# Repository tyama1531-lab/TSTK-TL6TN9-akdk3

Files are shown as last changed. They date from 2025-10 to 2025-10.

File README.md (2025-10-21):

# TSTK-TL6TN9

Generated by [Auto-Keyboard-Design-Kit](https://auto-kdk.pages.dev/)

## Preview

- 3D View

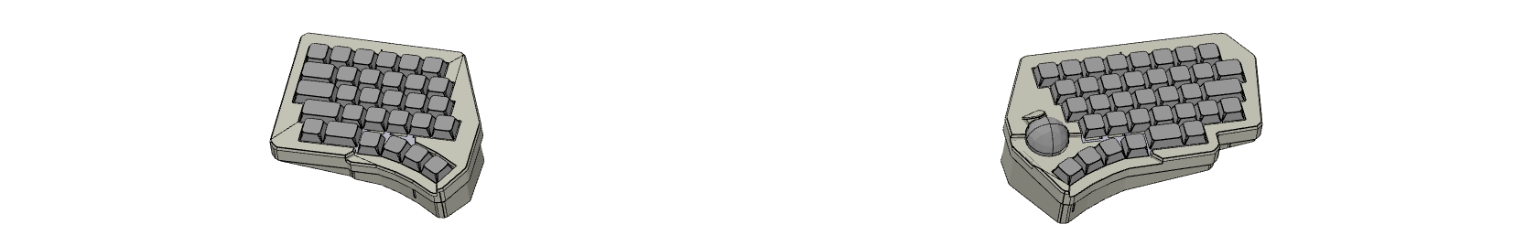
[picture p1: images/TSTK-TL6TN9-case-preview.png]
Case Preview


- Top View

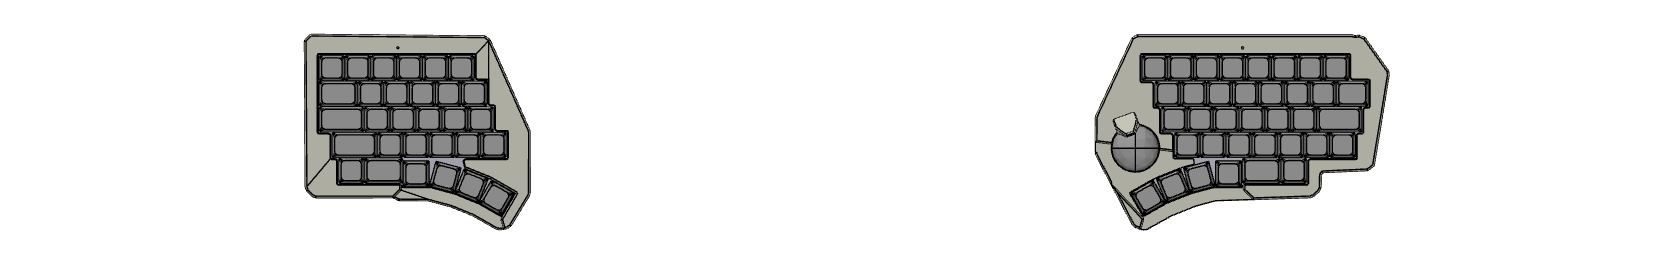
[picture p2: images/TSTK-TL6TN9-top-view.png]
Top View


## Parts List

|Part|Quantity|
|---|---|
|wireless controller|2|
|Conthrough(2.5mm, 9pin)|4|
|Battery|2|
USB-C cable|1|
|MX switch and MX socket|58|
|Choc V2 switch and Choc socket|8|
|Diode|66|
|Keycap|66|

## 機能

### PAW3222 トラックボール対応

このキーボードは右手側にPAW3222トラックボールを搭載し、高度な電源管理機能を備えています：

#### 🔋 電源管理
- **アイドルタイムアウト**: 5秒間操作がないと自動的にスリープモードに移行
- **スキャン頻度削減**: 非アクティブ時の消費電力を削減  
- **パワーコントロール**: ハードウェアレベルでのセンサーのスリープ/ウェイク制御

#### ⚙️ 設定オプション

以下の設定オプションが `boards/shields/tstk_tl6tn9/tstk_tl6tn9_right.conf` で利用可能です：

```properties
# PAW3222 アイドル・電源管理
CONFIG_PAW3222_IDLE_TIMEOUT_SECONDS=5     # アイドルタイムアウト（秒）
CONFIG_PAW3222_REDUCED_SCAN=y             # スキャン頻度削減を有効化
CONFIG_PAW3222_REDUCED_SCAN_MS=100        # 削減モード時のスキャン間隔（ミリ秒）
CONFIG_PAW3222_POWER_CTRL=y               # ハードウェア電源制御を有効化
```

#### 📊 デフォルト設定

| 設定項目 | 値 | 説明 |
|---|---|---|
| `IDLE_TIMEOUT_SECONDS` | 5 | アイドルモード移行までの時間 |
| `REDUCED_SCAN` | 有効 | モーションタイマーの最適化 |
| `REDUCED_SCAN_MS` | 100ms | スキャン頻度削減時のポーリング間隔 |
| `POWER_CTRL` | 有効 | ハードウェアスリープ/ウェイク制御 |

#### 🔧 カスタマイズ

電源管理の動作を変更するには：

1. `boards/shields/tstk_tl6tn9/tstk_tl6tn9_right.conf` を編集
2. CONFIG値を好みに応じて調整
3. `west build` でファームウェアを再ビルド

**バッテリー持続時間重視の設定例:**
```properties
CONFIG_PAW3222_IDLE_TIMEOUT_SECONDS=10    # より長いアイドルタイムアウト
CONFIG_PAW3222_REDUCED_SCAN_MS=200        # より遅いスキャン
```

**最大応答性重視の設定例:**
```properties
CONFIG_PAW3222_IDLE_TIMEOUT_SECONDS=30    # 最小限のアイドルタイムアウト
CONFIG_PAW3222_REDUCED_SCAN_MS=50         # より高速なスキャン
```

## ビルド方法

このファームウェアはwest ビルドシステムを使用するZMKとカスタムPAW3222ドライバーを使用しています。

### 前提条件
- West ビルド環境
- ZMK 開発環境のセットアップ

### ビルドコマンド
```bash
# 左手側ファームウェアのビルド
west build -b akdk_bt1 -- -DSHIELD=tstk_tl6tn9_left

# 右手側ファームウェアのビルド
west build -b akdk_bt1 -- -DSHIELD=tstk_tl6tn9_right

# 設定リセット用ファームウェア
west build -b akdk_bt1 -- -DSHIELD=settings_reset
```

### CI/CD
GitHub Actionsが push/PR 時に自動的にファームウェアをビルドします：
- 左手側: `tstk_tl6tn9_left-akdk_bt1-zmk.uf2`
- 右手側: `tstk_tl6tn9_right-akdk_bt1-zmk.uf2`  
- 設定リセット: `settings_reset-akdk_bt1-zmk.uf2`

## トラブルシューティング

### PAW3222 電源管理

**問題: アイドル後にトラックボールが反応しない**
- `CONFIG_PAW3222_POWER_CTRL=y` が有効になっているか確認
- アイドルタイムアウト設定を確認
- 電源状態の切り替えログを監視

**問題: バッテリー消耗が激しい**
- `CONFIG_PAW3222_IDLE_TIMEOUT_SECONDS` を増やす
- `CONFIG_PAW3222_REDUCED_SCAN_MS` を増やす
- `CONFIG_PAW3222_REDUCED_SCAN=y` が有効か確認

**問題: トラックボールの応答が遅い**
- `CONFIG_PAW3222_REDUCED_SCAN_MS` を減らす
- `CONFIG_PAW3222_IDLE_TIMEOUT_SECONDS` を減らす

### デバッグ
.conf` ファイルでデバッグログを有効化：

注: このリポジトリではログ設定は共通設定ファイル `config/prj.conf` に集約されています。個別のシールド設定（`boards/shields/.../*.conf`）で上書きすることも可能ですが、基本は `config/prj.conf` を編集してください。

```properties
# 有効にする場合（例）
CONFIG_ZMK_LOG_LEVEL_DBG=y
CONFIG_ZMK_USB_LOGGING=y
```

PAW3222関連のログメッセージを確認：
- `PAW32XX: idle timeout reached, entering idle`
- `PAW32XX: motion detected while idle -> waking up`
- `PAW32XX: sensor set to sleep`
- `PAW32XX: sensor wake request succeeded`

## ライセンス

[ライセンス情報をここに記載]

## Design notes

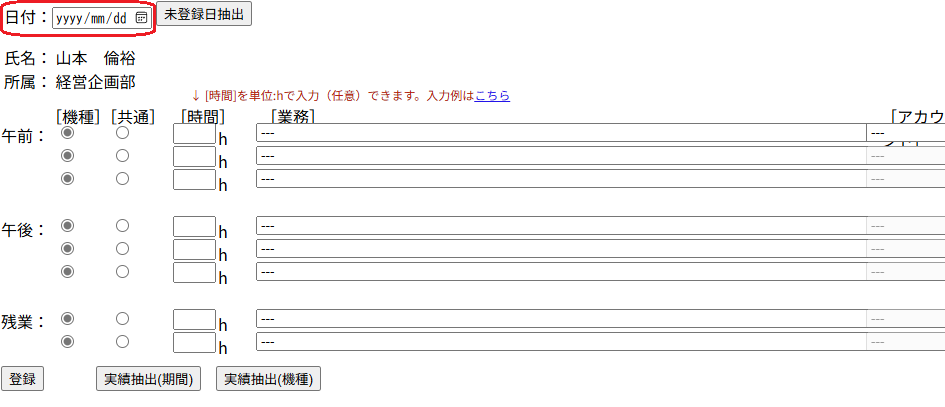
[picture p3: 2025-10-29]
images/Edgeモードで開いた画面.bmp

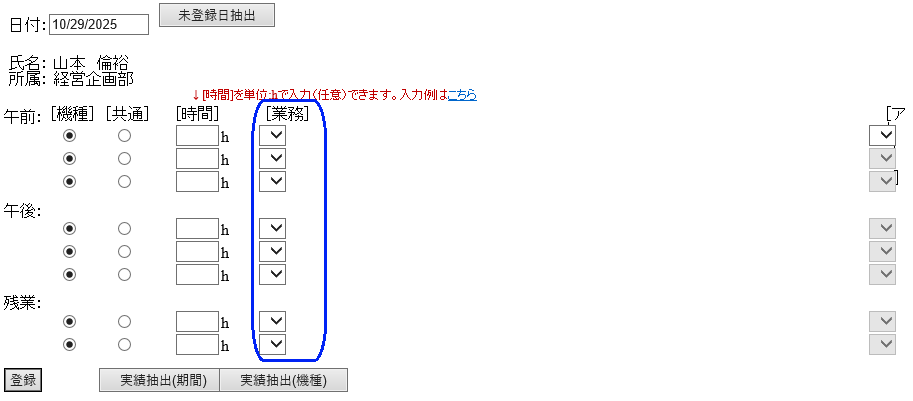
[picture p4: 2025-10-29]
images/IEモードで開いた画面.bmp

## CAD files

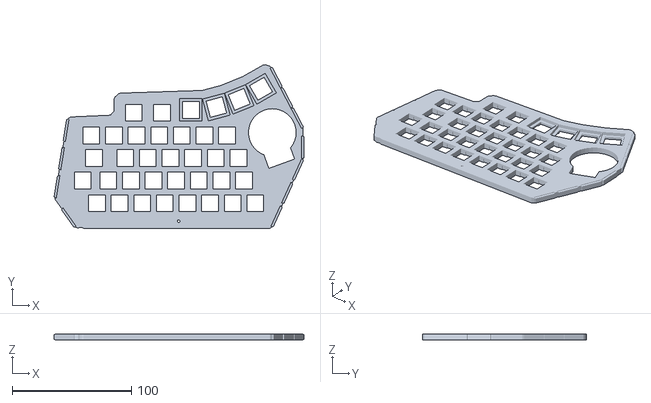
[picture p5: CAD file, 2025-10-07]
case/TSTK-TL6TN9-right-plate.stl
209.9 x 137.4 x 5.00

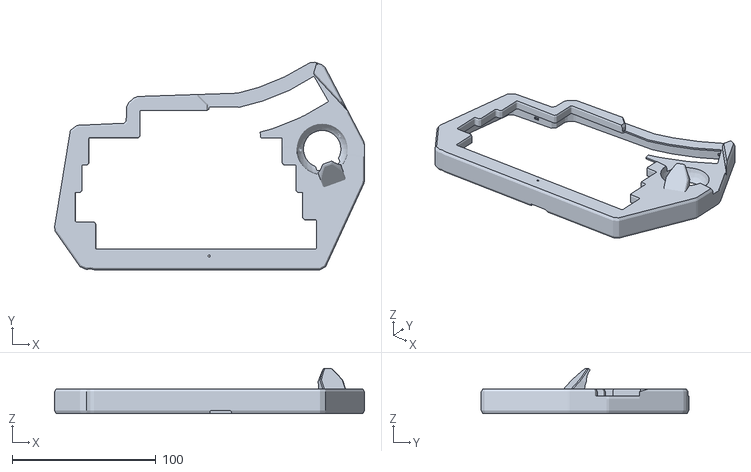
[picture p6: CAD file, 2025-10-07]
case/TSTK-TL6TN9-right-top-case.stl
215.6 x 144.3 x 31.3

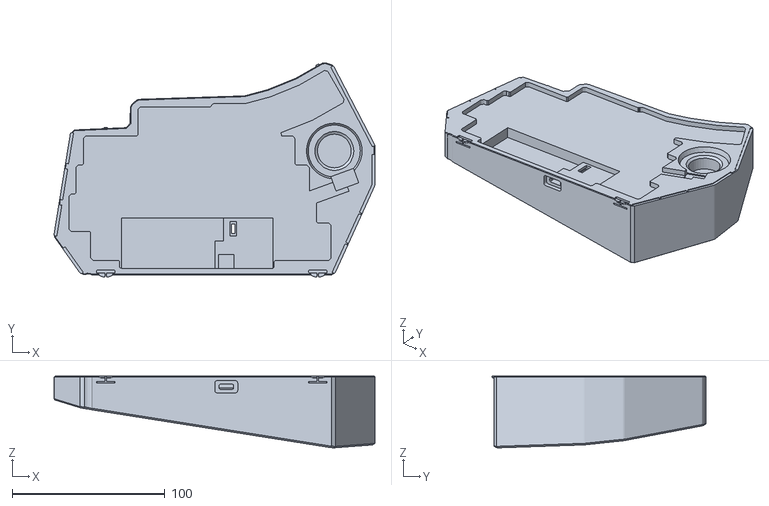
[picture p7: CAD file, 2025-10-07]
case/TSTK-TL6TN9-right-bottom-case.stl
210.0 x 140.2 x 47.0

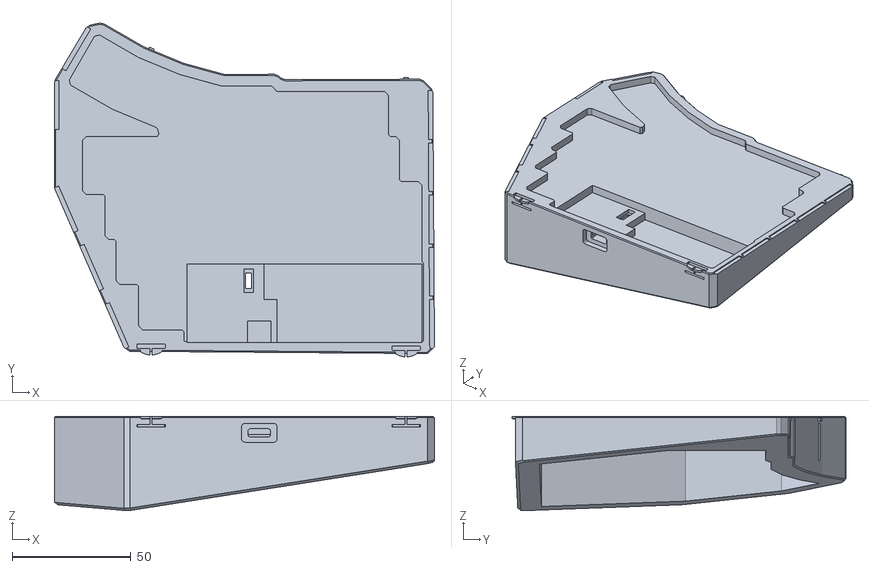
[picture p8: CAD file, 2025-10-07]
case/TSTK-TL6TN9-left-bottom-case.stl
160.1 x 140.6 x 39.8

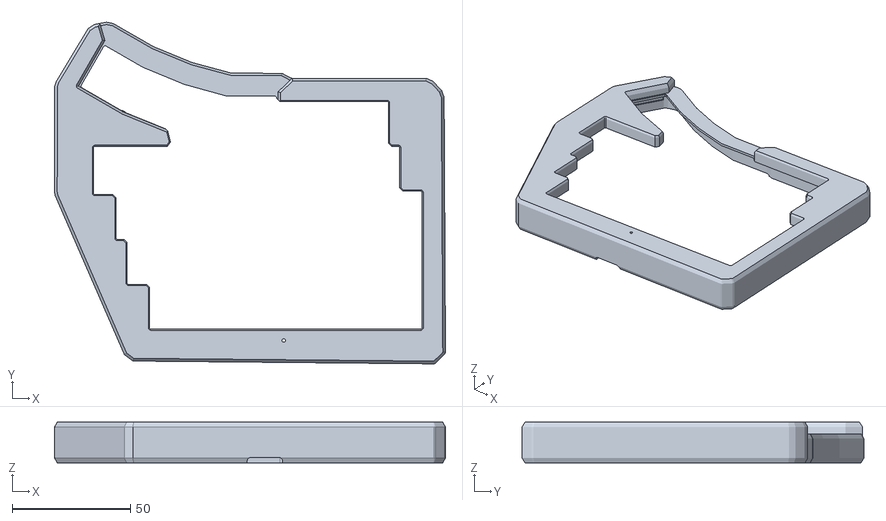
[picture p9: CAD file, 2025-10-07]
case/TSTK-TL6TN9-left-top-case.stl
165.6 x 144.7 x 17.2

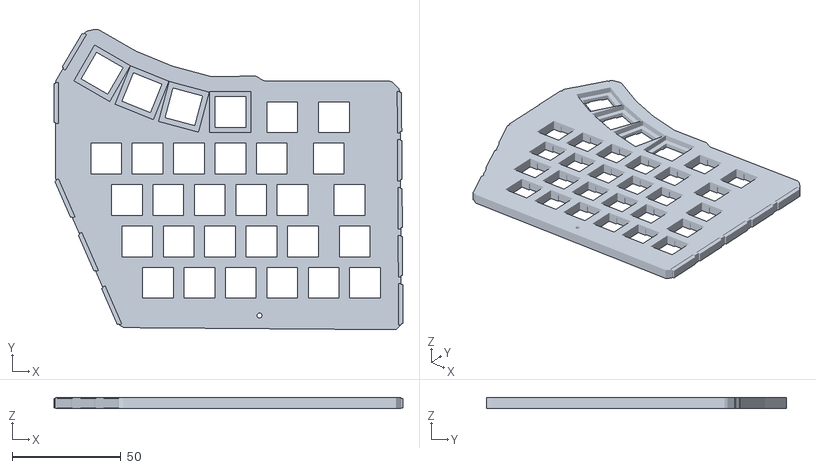
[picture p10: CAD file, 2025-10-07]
case/TSTK-TL6TN9-left-plate.stl
160.1 x 137.8 x 5.00

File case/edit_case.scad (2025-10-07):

union() {
  difference() {
    import("case.stl");
    translate([75, 32, 6.5]) cube([30, 45, 10]); // 出っ張り削除
  }

  // 補完形状をZ軸まわりに45度回転して配置
  color("red")
  translate([112.730, 15.564, 5.5])//5.3
  rotate([0, 0, 117.48])
  cube([58, 5, 1.0]);//1.2
  
  translate([112.730, 15.564, 3.5])
  rotate([0, 0, 117.48])
  cube([30, 1.748, 3]);
    
  translate([110.6810, 13.214, 4.5])
  rotate([0, 0, 12.21])
  cube([2.5, 1.8631, 2.0]);
}

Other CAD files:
case/TSTK-TL6TN9-right-top-case_mod2.stl
case/TSTK-TL6TN9-right-top-case_mod1.stl

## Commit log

2025-10-12 _right.confへ定義追加
2025-10-12 chosen ノードにUSBログの送信先を明示
2025-10-12 UARTコンソール関連を無効化
2025-10-12 CONFIG_UART_CONSOLE=nをleft.confと_defconfigに追加しキャッシュ削除
2025-10-12 build.ymlにpip installのstepを追加
2025-10-12 キャッシュ削除工程などやめて現状ビルド
2025-10-12 .conf出力確認step追加
2025-10-12 .conf出力確認step追加（修正）
2025-10-12 .conf出力確認step追加（修正2）
2025-10-12 .conf出力確認step追加（修正3）
2025-10-12 .conf出力確認step追加（修正4）
2025-10-12 Revert "chosen ノードにUSBログの送信先を明示"
    This reverts commit cae7e07133bdf2f2731665f7522d1419618e9480.
2025-10-12 chosen ノードにUSBログの送信先を明示（状態を戻す）
2025-10-12 CONFIG_ZMK_USB_LOGGING=y設定前の初期状態に戻す
2025-10-12 CONFIG_ZMK_LOG_LEVEL_DBG=yとCONFIG_ZMK_USB_LOGGING=y
2025-10-12 chosenにzephyr,console = &usbd;明記
2025-10-12 _left.confにもCONFIG_ZMK_LOG_LEVEL_DBG=yとCONFIG_ZMK_USB_LOGGING=y
2025-10-12 UARTを左右.confで無効化
2025-10-12 _leftと_right.overlayに&uart0 {status="disabled";}
2025-10-12 Pushされていなかったので再Push
2025-10-12 prj.confを新設して共通のCONFIG_設定を移動
2025-10-12 snippetの書き方を配列に変更
2025-10-12 prj.conf削除し_left.confto_right.conf記述に戻す
2025-10-12 CONFIG_UART関係=nを削除
2025-10-12 UART関連のバグ対応
2025-10-12 branchをfeature/seamless-xy-scroll-3に設定してビルド
2025-10-13 get_input_mode_for_current_layerでモード確認
2025-10-13 cfg->bothscroll_layersのデバッグログ
2025-10-13 switch (data->current_mode)の詳細ログ
2025-10-13 layer切替_詳細ログ
2025-10-13 bothscrollのマクロ展開コード追加
2025-10-13 XYシームレススクロール実装完でデバッグログ行をコメントアウト
2025-10-13 ログ出力OFF
2025-10-19 安定版に戻す
2025-10-20 chore(manifest): point paw3222 driver to main (merged fix)
2025-10-20 build.ymlシンプル化
2025-10-20 Add PAW3222 idle/reduced-scan/power-ctrl configs
    - Add CONFIG_PAW3222_IDLE_TIMEOUT_SECONDS=5 to right side only
    - Add CONFIG_PAW3222_REDUCED_SCAN=y for motion timer optimization
    - Add CONFIG_PAW3222_REDUCED_SCAN_MS=100 for scan interval
    - Add CONFIG_PAW3222_POWER_CTRL=y for low-power mode support
    - Remove duplicate configs from prj.conf and left.conf
    - Centralize PAW3222 settings on right side (sensor location)
2025-10-20 docs: Add comprehensive PAW3222 power management documentation
    - Add Features section with power management overview
    - Document all CONFIG options with examples
    - Include customization examples for battery vs responsiveness
    - Add building instructions and CI/CD info
    - Provide troubleshooting guide and debugging tips
    - Cover idle timeout, reduced scan, and power control features
2025-10-20 fix: resolve critical PAW3222 runtime issues
    - Fix idle recovery: trackball now remains responsive after timeout
    - Fix scan frequency: use 15ms during normal operation, not 100ms
    - Ensures smooth cursor movement without jerky behavior
    - Maintains power management benefits during actual idle state
2025-10-20 trigger: rebuild with fixed PAW3222 driver
    - Driver fixes for idle recovery and scan frequency are now applied
    - Force rebuild to test runtime issue fixes
    - Ready for final verification and testing
2025-10-20 fix: improve Zephyr module configuration for board detection
    - Add cmake-ext and dts_root settings to zephyr/module.yml
    - Should resolve 'Invalid BOARD' error in CI builds
    - Ensures akdk_bt1 board is properly detected by ZMK build system
2025-10-20 fix: critical idle recovery fix - keep IRQ enabled
    - Driver updated to keep GPIO IRQ active during idle
    - Ensures trackball can wake up from idle state properly
    - Should resolve unresponsive trackball after 5-second timeout
    - Ready for final verification testing
2025-10-20 prod: disable debug logging for production release
    - Set log level to WARNING only for normal operation
    - Keep PAW3222 power management features enabled
    - Ready for main branch merge and production use
    - All functionality tested and verified working
2025-10-21 ci: point paw3222 driver to main in config/west.yml
2026-03-04 version固定
2026-03-04 west.ymlでバージョン固定
